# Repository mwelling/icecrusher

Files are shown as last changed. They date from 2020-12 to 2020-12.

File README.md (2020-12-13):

# icebreaker++ RAM

The icebreaker is a friendly development board for the iCE40: [https://github.com/icebreaker-fpga/icebreaker](https://github.com/icebreaker-fpga/icebreaker)

---

## What is it

The icebreaker is a really nice and handy little board. But it has a small flaw, the ice40 FPGA it uses is quite smol, while it's often fun to see the exciting projects people pull off with 5k LUTs. Sometimes it's handy to have a bit of extra space available whe experimenting.

 - The board design takes the original designs and simply replaces the fpga with an ECP5.
 - The FTDI's second port is connected directly to extra I/O pins.
 - Each PMOD is connected to support 4x differential-pairs each.
 - Features footprints for both PSRAM and HyperRAM.

## Folder structure

```
kicad-src: KiCad v6 source files
production:
 - Gerbers:      [project]_gerbers.zip
 - Schematic:    [project].pdf
 - Board render: [project].png
```

## Render

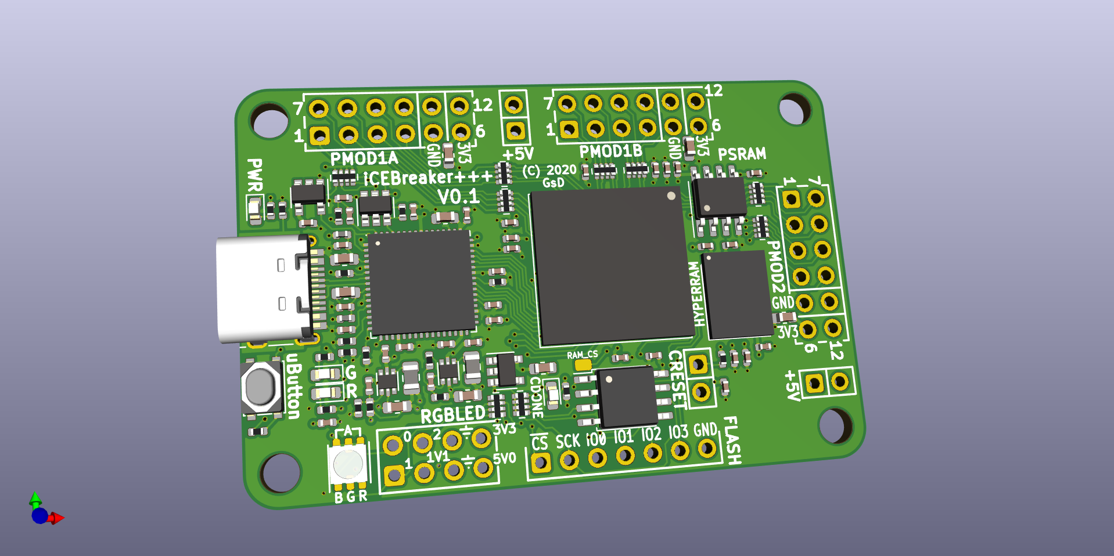
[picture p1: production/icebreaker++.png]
Render


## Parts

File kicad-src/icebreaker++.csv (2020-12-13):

C1 C4 C10 C12 C13 C14 C16 C17 C18 C19 C20 C21 C22 | 13 | 100n | Capacitor_SMD:C_0402_1005Metric |  | cap-cer-0402-100n | ANY
C15 C23 | 2 | 4.7uF | Capacitor_SMD:C_0402_1005Metric | ~ |  |  |  |  |  |  |  | Yageo | CC0402KRX5R6BB475
C2 C3 C5 C8 C11 C35 C36 C37 C38 C39 C40 C41 C42 C43 | 14 | 0.1uF | Capacitor_SMD:C_0402_1005Metric | ~
C24 C28 C29 | 3 | 10uF | Capacitor_SMD:C_0603_1608Metric | ~ |  |  |  |  |  |  |  | Yageo | CC0603KRX5R5BB106
C25 C30 C31 | 3 | 1uF | Capacitor_SMD:C_0402_1005Metric | ~ |  |  |  |  |  |  |  | Yageo | CC0402KRX5R6BB105
C26 C27 | 2 | 6.8pF | Capacitor_SMD:C_0402_1005Metric | ~ |  |  |  |  |  |  |  | Yageo | CC0402CRNPO9BN6R8
C32 C33 C34 | 3 | DNP | Capacitor_SMD:C_0603_1608Metric |  | cap-cer-0603-10u | ANY | YES
C6 C7 C9 | 3 | 4u7 | Capacitor_SMD:C_0603_1608Metric |  | cap-cer-0402-4u7 | ANY
D1 D4 | 2 | GRN | LED_SMD:LED_0603_1608Metric |  | led-0603-grn | ANY
D11 | 1 | LED_RGB | pkl_led:LED_Cree_PLCC6_3.4x3.4mm | ~ |  |  | YES | CLX6F-FKC | Cree
D3 | 1 | BLU | LED_SMD:LED_0603_1608Metric |  | led-0603-blu | ANY
D5 | 1 | RED | LED_SMD:LED_0603_1608Metric |  | led-0603-red | ANY
J20 | 1 | Flash | Connector_PinHeader_2.54mm:PinHeader_1x07_P2.54mm_Vertical | ~ | conn-th-01in-7-1-hdr | ANY
J21 J23 J27 | 3 | PMOD | gsd-footprints:PMOD_Angled_2x06 | ~ | conn-th-01in-6-2-rec-ra | ANY
J22 J26 | 2 | 5V AUX | Connector_PinHeader_2.54mm:PinHeader_2x01_P2.54mm_Vertical | ~ | conn-th-01in-2-1-hdr | ANY
J24 | 1 | USB_C_Receptacle_USB2.0 | Connector_USB:USB_C_Receptacle_HRO_TYPE-C-31-M-12 | https://www.usb.org/sites/default/files/documents/usb_type-c.zip
J25 | 1 | RGB Led | Connector_PinHeader_2.54mm:PinHeader_2x04_P2.54mm_Vertical | ~ | conn-th-01in-4-2-hdr | ANY
J28 | 1 | CRESET | Connector_PinHeader_2.54mm:PinHeader_2x01_P2.54mm_Vertical | ~ | conn-th-01in-2-1-hdr | ANY | YES
L1 L2 | 2 | 600 | Inductor_SMD:L_0402_1005Metric |  | ferrite-0402-600 | ANY
L3 L4 | 2 | 2.2uH | Inductor_SMD:L_0805_2012Metric | ~ |  |  |  |  |  |  |  | Sunltech Tech | SLM20122R2MIT
P2 P3 P4 P5 | 4 | UP | pkl_pads:PAD_SMD_1x2.65 |  |  | ANY
P6 | 1 | RAM_CS | pkl_pads:PAD_SMD_1x1.5 |  |  | ANY
R1 | 1 | 1M | Resistor_SMD:R_0402_1005Metric |  | res-0402-1m | ANY
R10 | 1 | 210k | Resistor_SMD:R_0402_1005Metric | ~ |  |  |  |  |  |  |  | Yageo | RC0402FR-07210KL | 1%
R2 R11 | 2 | 10k | Resistor_SMD:R_Array_Convex_4x0402 | ~
R20 | 1 | 1k | Resistor_SMD:R_0402_1005Metric |  | res-0402-10k | ANY
R21 R22 | 2 | 5.1k | Resistor_SMD:R_0402_1005Metric | ~
R23 | 1 | 47k | Resistor_SMD:R_0402_1005Metric | ~ |  |  |  |  |  |  |  | Yageo | RC0402FR-0747KL
R24 | 1 | 84k5 | Resistor_SMD:R_0402_1005Metric | ~ |  |  |  |  |  |  |  | Yageo | RC0402FR-0784K5L | 1%
R26 | 1 | 100k | Resistor_SMD:R_0402_1005Metric | ~ |  |  |  |  |  |  |  | Yageo | RC0402FR-07100KL | 1%
R3 R4 R7 R16 R17 R18 R27 | 7 | 33R | Resistor_SMD:R_Array_Convex_4x0402 | ~
R5 R14 R15 | 3 | 330E | Resistor_SMD:R_0402_1005Metric |  | res-0402-330 | ANY
R6 R12 | 2 | 2k2 | Resistor_SMD:R_0402_1005Metric |  | res-0402-2k2 | ANY
R8 | 1 | 12k | Resistor_SMD:R_0402_1005Metric |  | res-0402-12k | ANY |  |  |  | 1% current reference
R9 R13 R19 R25 | 4 | 10k | Resistor_SMD:R_0402_1005Metric |  | res-0402-10k | ANY
SW1 | 1 | TACT | Button_Switch_SMD:SW_SPST_PTS810 |  | sw-tact-top-3x4x25
U1 | 1 | 93C46B-SOT-23-6 | Package_TO_SOT_SMD:SOT-23-6 | http://ww1.microchip.com/downloads/en/DeviceDoc/20001749K.pdf | eeprom-sot23-6-93c46b | ANY |  | 93C46B |  | EEPROM 1KBit 2MHz SOT-23-6
U10 | 1 | IS66WVH16M8ALL | gsd-footprints:BGA-24_8.0x6.0mm_Layout5x5_P0.8mm_Pad0.35mm_NSMD |  |  |  |  |  |  |  |  | ISSI, Integrated Silicon Solution Inc | IS66WVH16M8ALL-166B1LI |  | 706-1548-ND
U2 | 1 | FT2232H | Package_DFN_QFN:QFN-64-1EP_9x9mm_P0.5mm_EP4.35x4.35mm | https://www.ftdichip.com/Support/Documents/DataSheets/ICs/DS_FT2232H.pdf
U3 | 1 | W25Q32JVSS | Package_SO:SOIC-8_5.23x5.23mm_P1.27mm | http://www.winbond.com/resource-files/w25q32jv%20revg%2003272018%20plus.pdf
U4 U5 | 2 | TLV62569DRL | Package_TO_SOT_SMD:SOT-666 | http://www.ti.com/lit/ds/symlink/tlv62569.pdf |  |  |  |  |  |  |  | Texas Instruments | TLV62569DRLR
U6 | 1 | TLV713285PDBV | Package_TO_SOT_SMD:SOT-23-5 | http://www.ti.com/lit/ds/symlink/tlv713p.pdf
U7 | 1 | 12MHz | Package_TO_SOT_SMD:SOT-23-5 |  | xtal-sot23-5-12mhz-osc | ANY
U8 | 1 | ECP5U-12-CABGA256 | Package_BGA:BGA-256_14.0x14.0mm_Layout16x16_P0.8mm_Ball0.45mm_Pad0.32mm_NSMD |  |  |  |  |  |  |  | ECP5U_12
U9 | 1 | LY68L6400SLIT | Package_SO:SOIC-8_3.9x4.9mm_P1.27mm | http://www.winbond.com/resource-files/w25q32jv%20revg%2003272018%20plus.pdf

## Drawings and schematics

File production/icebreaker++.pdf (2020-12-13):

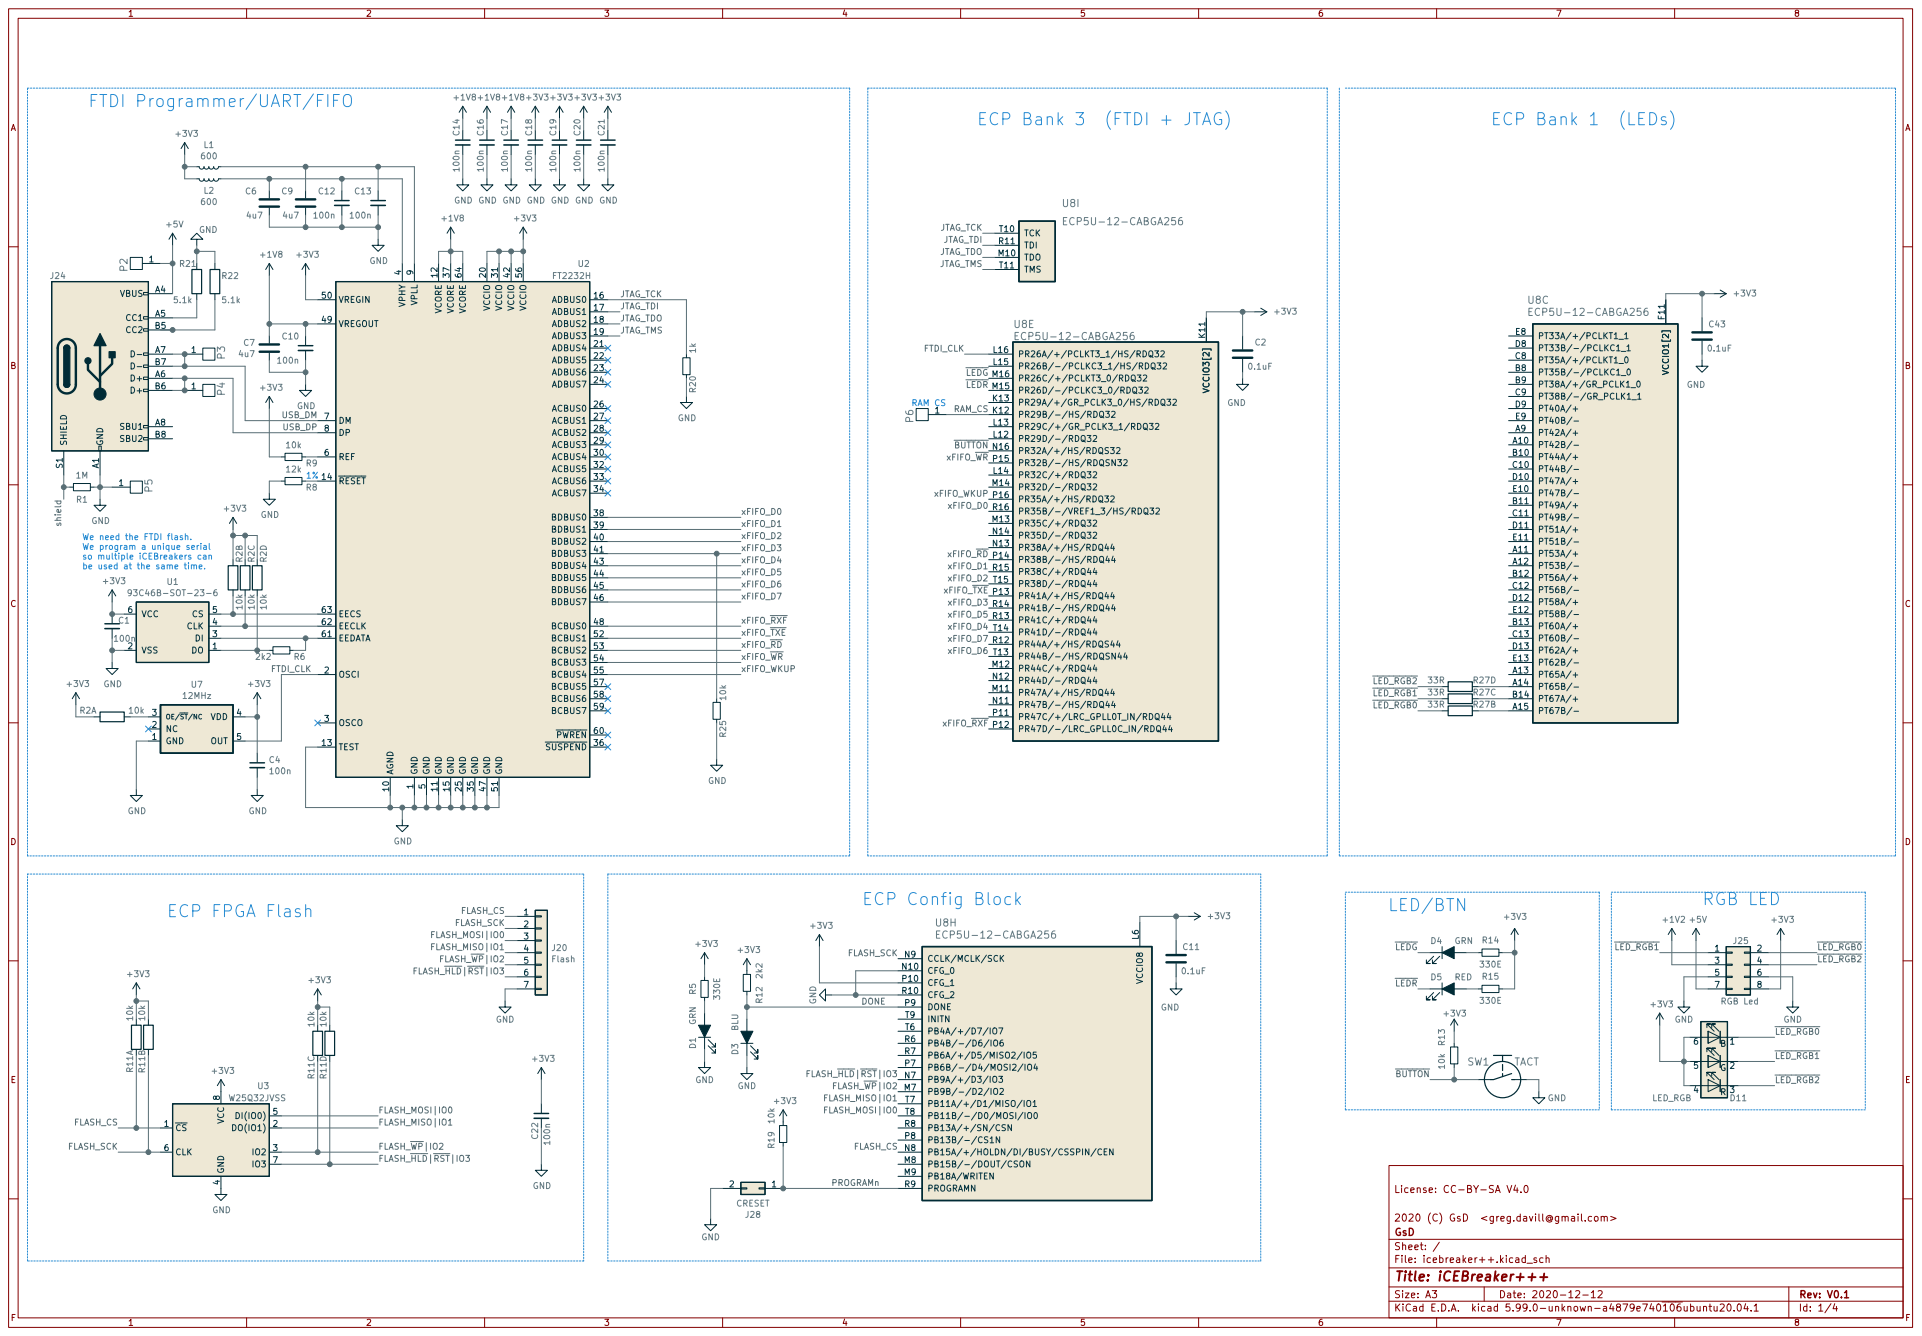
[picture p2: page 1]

ECP Bank 3 (FTDI + JTAG)

1 AGND 10 GND 11 VCORE 12 TEST 13 ~RESET 14 GND 15 ADBUS0 16 ADBUS1 17 ADBUS2 18 ADBUS3 19 OSCI 2 VCCIO 20 ADBUS4 21 ADBUS5 22 ADBUS6 23 ADBUS7 24 GND 25 ACBUS0 26 ACBUS1 27 ACBUS2 28 ACBUS3 29 OSCO 3 ACBUS4 30 VCCIO 31 ACBUS5 32 ACBUS6 33 ACBUS7 34 GND 35 ~SUSPEND 36 VCORE 37 BDBUS0 38 BDBUS1 39 VPHY

4 BDBUS2 40 BDBUS3 41 VCCIO 42 BDBUS4 43 BDBUS5 44 BDBUS6 45 BDBUS7 46 GND 47 BCBUS0 48 VREGOUT 49 GND

5 VREGIN 50 GND 51 BCBUS1 52 BCBUS2 53 BCBUS3 54 BCBUS4 55 VCCIO 56 BCBUS5 57 BCBUS6 58 BCBUS7 59 REF 6 ~PWREN 60 EEDATA 61 EECLK 62 EECS 63 VCORE 64 DM 7 DP 8 VPLL

We need the FTDI flash. We program a unique serial

so multiple iCEBreakers can
be used at the same time. ECP FPGA Flash

2020 (C) GsD <greg.davill@gmail.com>
File: icebreaker++.kicad_sch Sheet: / GsD

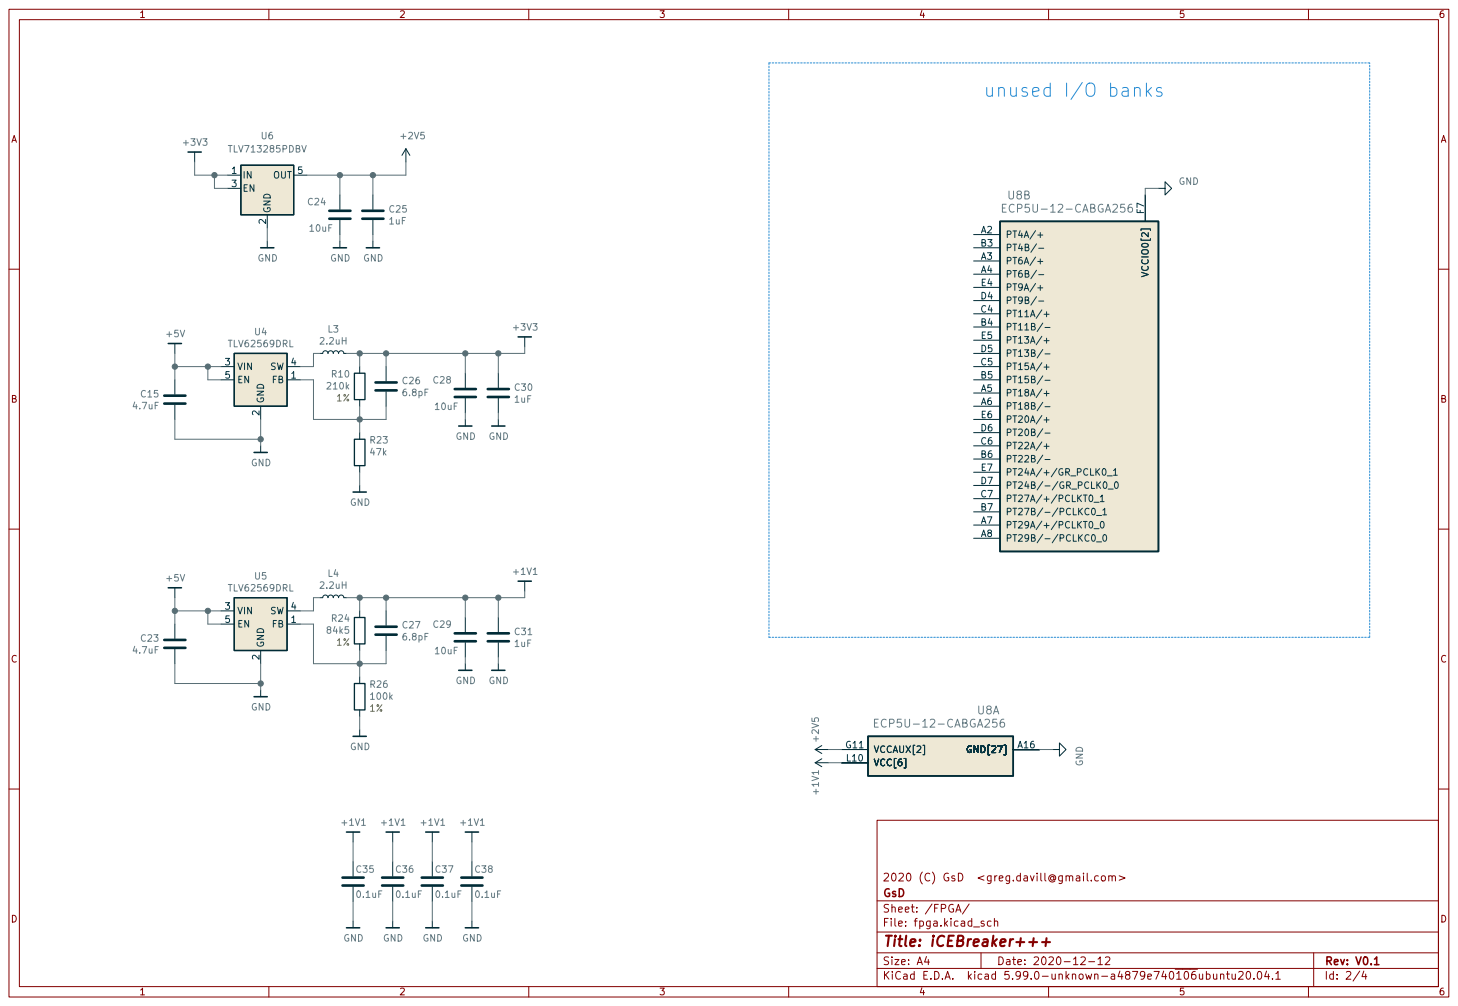
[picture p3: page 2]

2020 (C) GsD <greg.davill@gmail.com> GND

File: fpga.kicad_sch Sheet: /FPGA/ GsD

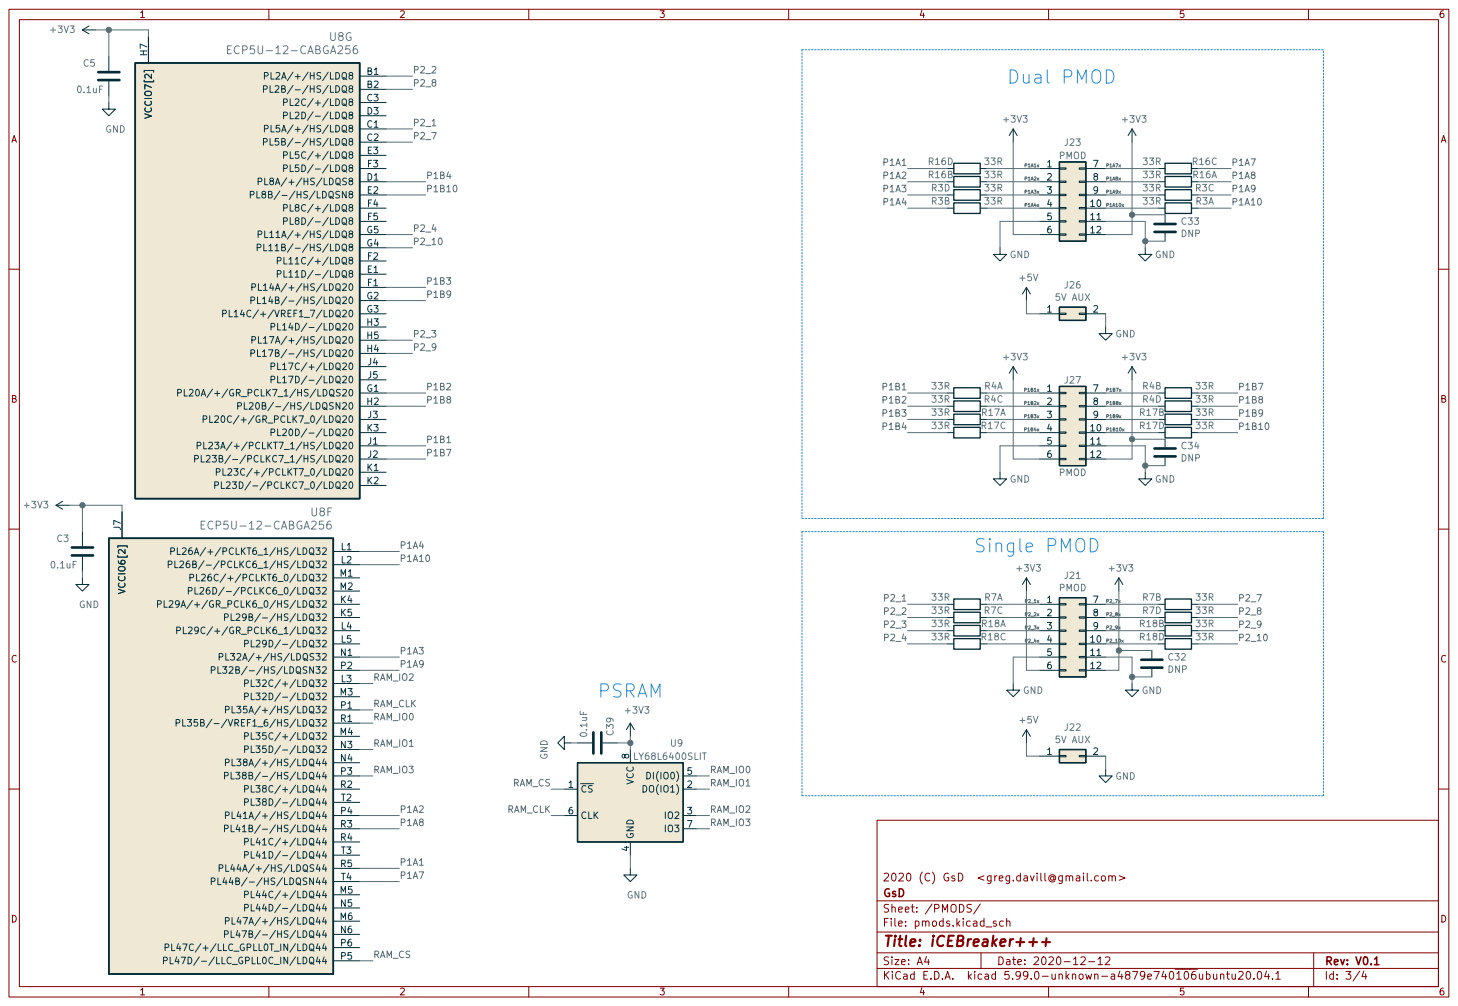
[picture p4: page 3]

2020 (C) GsD <greg.davill@gmail.com> GND

File: pmods.kicad_sch Sheet: /PMODS/ GsD

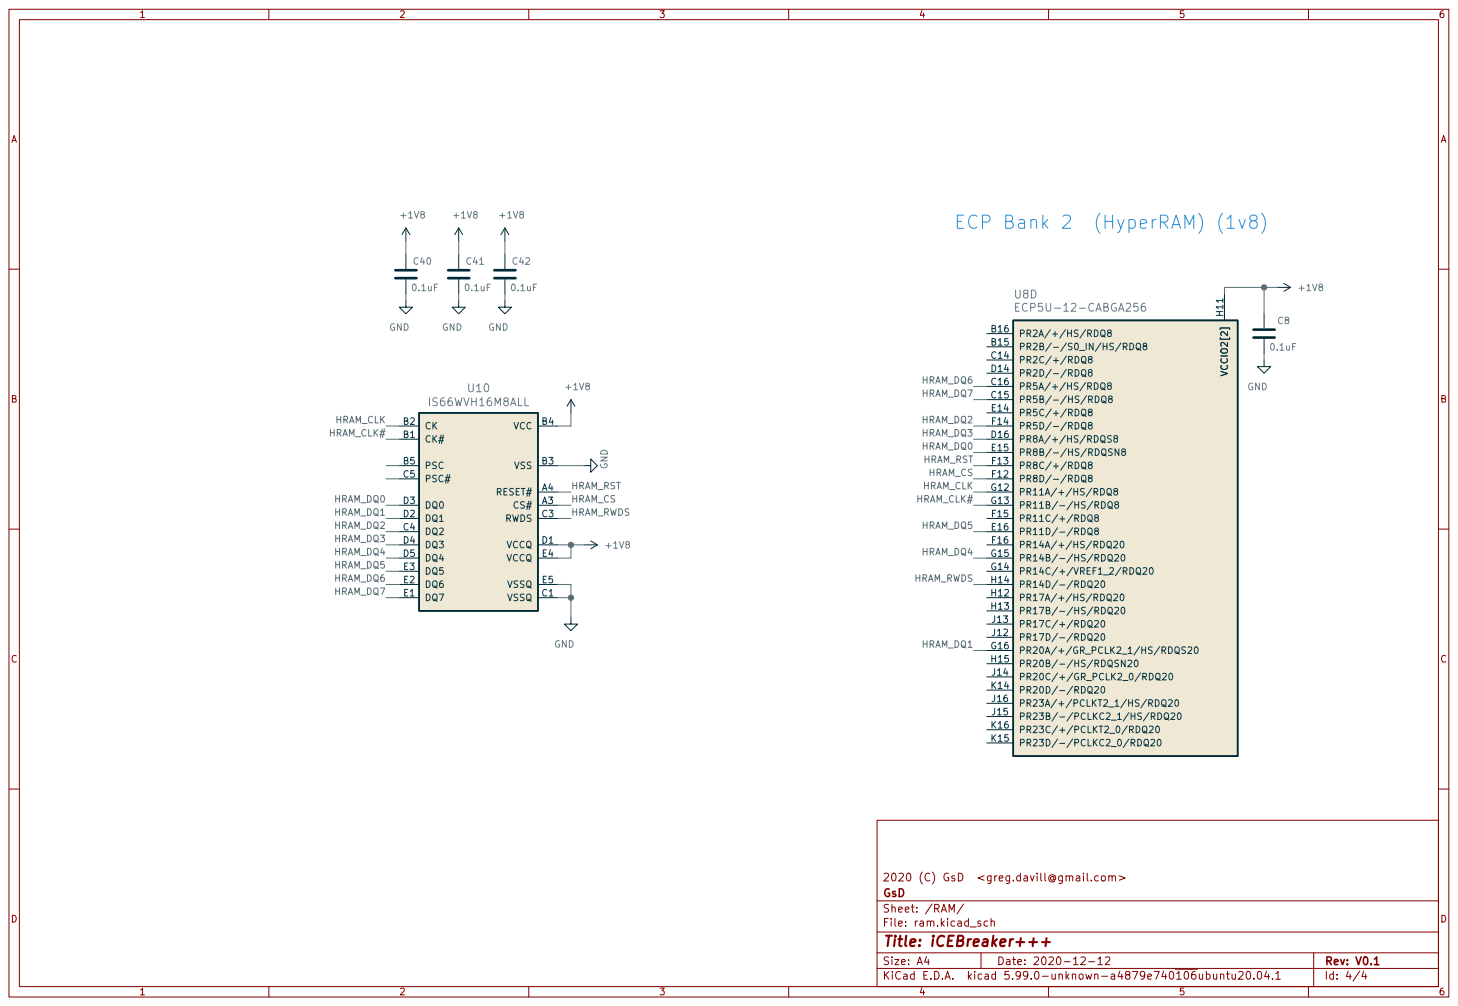
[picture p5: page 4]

2020 (C) GsD <greg.davill@gmail.com>
File: ram.kicad_sch Sheet: /RAM/ GsD

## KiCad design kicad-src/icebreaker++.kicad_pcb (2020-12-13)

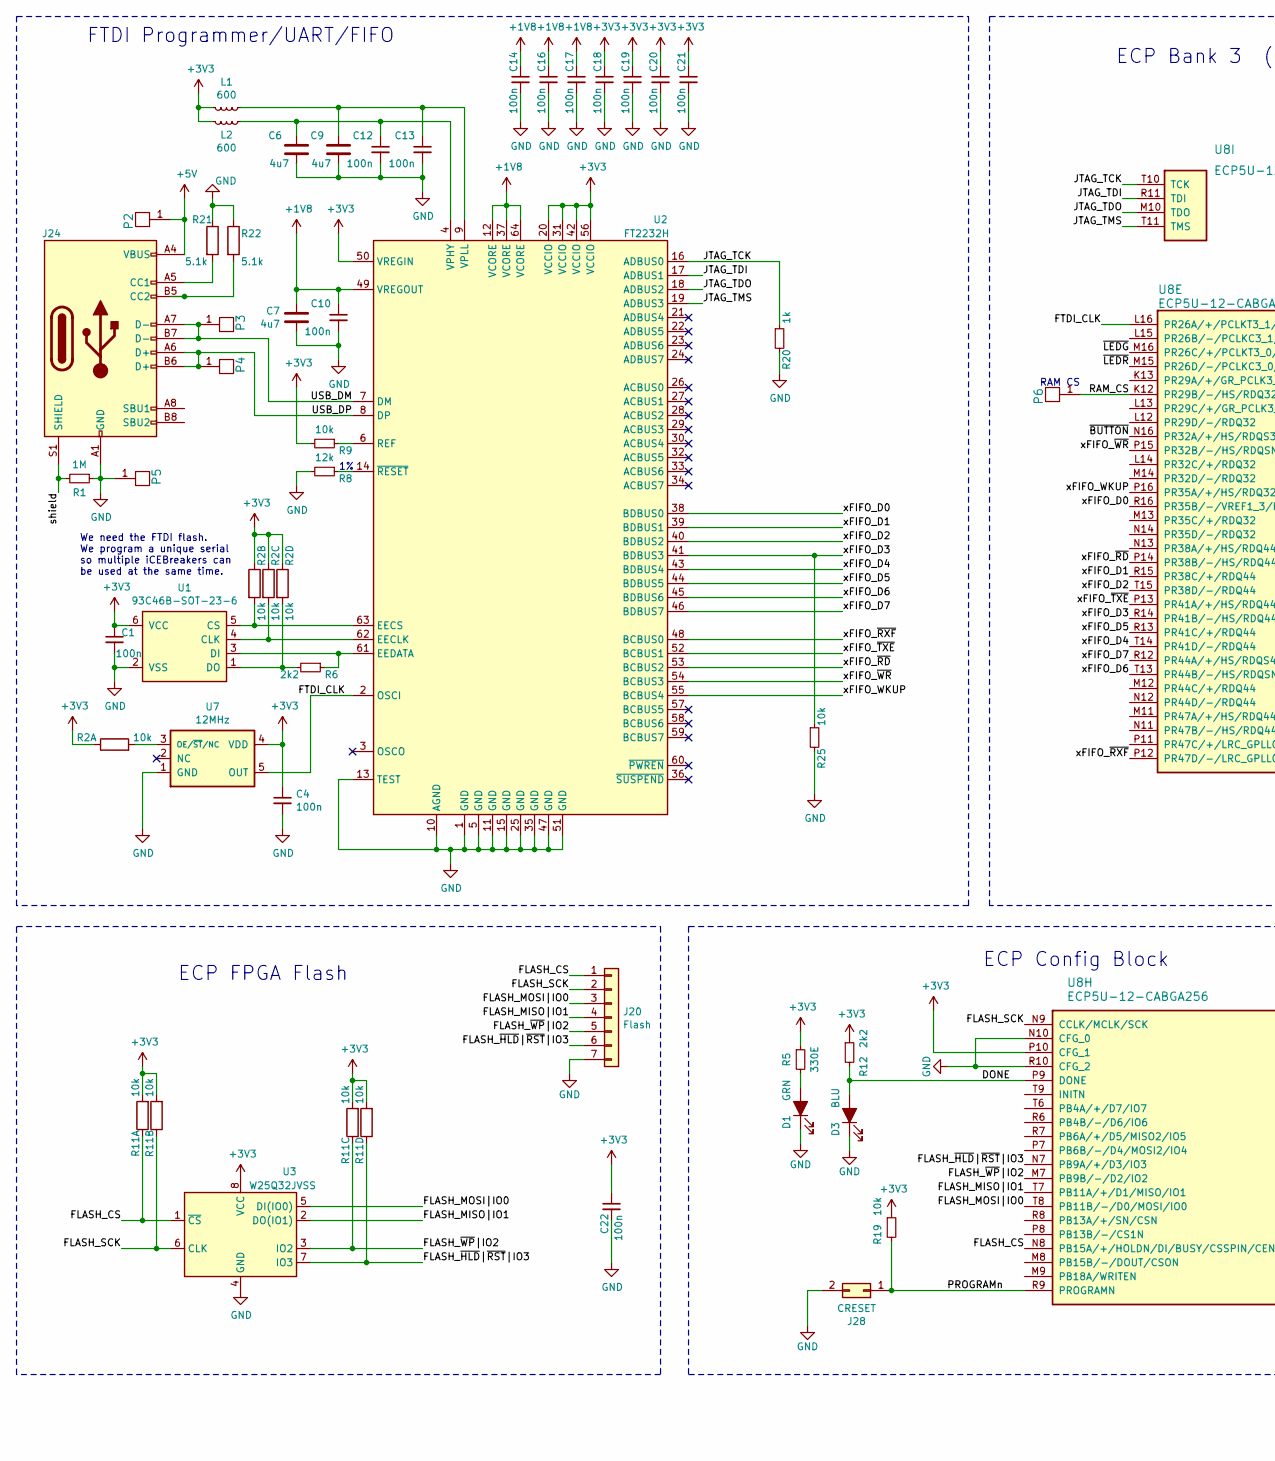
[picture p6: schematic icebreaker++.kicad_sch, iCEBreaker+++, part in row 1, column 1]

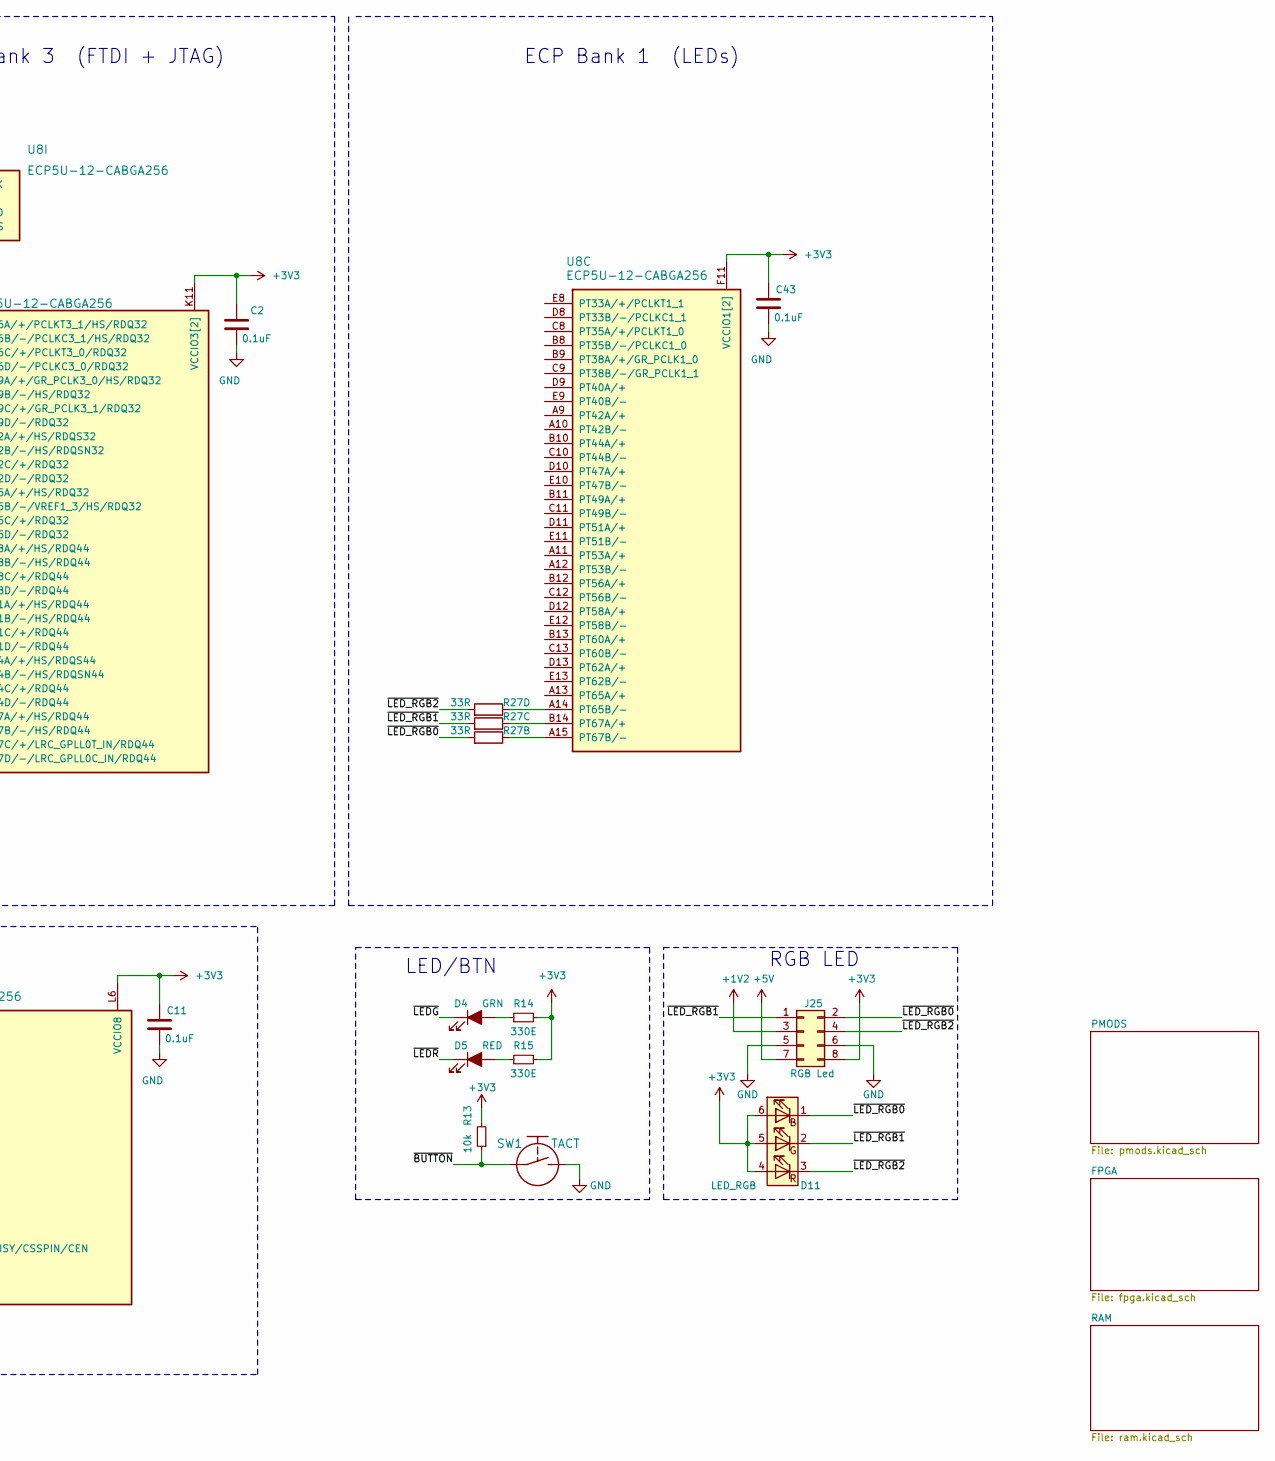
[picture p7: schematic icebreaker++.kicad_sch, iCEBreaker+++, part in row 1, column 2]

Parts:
C1, C4, C10, C12, C13, C14, C16, C17, C18, C19, C20, C21, C22: 100n; C_0402_1005Metric
C2, C11, C43: 0.1uF; C_0402_1005Metric
C6, C7, C9: 4u7; C_0603_1608Metric
D1, D4: GRN; LED_0603_1608Metric
D3: BLU; LED_0603_1608Metric
D5: RED; LED_0603_1608Metric
D11: LED_RGB; LED_Cree_PLCC6_3.4x3.4mm
J20: Flash; PinHeader_1x07_P2.54mm_Vertical
J24: USB_C_Receptacle_USB2.0; USB_C_Receptacle_HRO_TYPE-C-31-M-12
J25: RGB Led; PinHeader_2x04_P2.54mm_Vertical
J28: CRESET; PinHeader_2x01_P2.54mm_Vertical
L1, L2: 600; L_0402_1005Metric
P2, P3, P4, P5: UP; PAD_SMD_1x2.65
P6: RAM_CS; PAD_SMD_1x1.5
R1: 1M; R_0402_1005Metric
R2, R11: 10k; R_Array_Convex_4x0402
R5, R14, R15: 330E; R_0402_1005Metric
R6, R12: 2k2; R_0402_1005Metric
R8: 12k; R_0402_1005Metric
R9, R13, R19, R25: 10k; R_0402_1005Metric
R20: 1k; R_0402_1005Metric
R21, R22: 5.1k; R_0402_1005Metric
R27: 33R; R_Array_Convex_4x0402
SW1: TACT; SW_SPST_PTS810
U1: 93C46B-SOT-23-6; SOT-23-6
U2: FT2232H; QFN-64-1EP_9x9mm_P0.5mm_EP4.35x4.35mm
U3: W25Q32JVSS; SOIC-8_5.23x5.23mm_P1.27mm
U7: 12MHz; SOT-23-5
U8: ECP5U-12-CABGA256; BGA-256_14.0x14.0mm_Layout16x16_P0.8mm_Ball0.45mm_Pad0.32mm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

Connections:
+1V2: J25.3
+1V8: C7.1, C10.1, C14.1, C16.1, C17.1, U2.12 (VCORE), U2.37 (VCORE), U2.49 (VREGOUT), U2.64 (VCORE); also elsewhere on the board
+3V3: C1.1, C2.1, C4.1, C11.1, C18.1, C19.1, C20.1, C21.1, C22.1, C43.1, D11.4 (BA), D11.5 (GA), D11.6 (RA), J25.8, L1.1, L2.1, R2.5, R2.6, R2.7, R2.8, R5.1, R9.2, R11.1, R11.2, R11.3, R11.4, R12.1, R13.2, R14.2, R15.2, R19.1, U1.6 (VCC), U2.20 (VCCIO), U2.31 (VCCIO), U2.42 (VCCIO), U2.50 (VREGIN), U2.56 (VCCIO), U3.8 (VCC), U7.4 (VDD), U8.F10 (VCCIO1[2]), U8.F11 (VCCIO1[2]), U8.K11 (VCCIO3[2]), U8.L6 (VCCIO8), U8.L11 (VCCIO3[2]), U8.P10 (CFG_1); also elsewhere on the board
+5V: J24.A4 (VBUS), J24.A9 (VBUS), J24.B4 (VBUS), J24.B9 (VBUS), J25.7, P2.1 (PAD); also elsewhere on the board
/DONE: D3.2 (A), R12.2, U8.P9 (DONE)
/FLASH_CS: J20.1, R11.8, U3.1 (~CS), U8.N8 (PB15A/+/HOLDN/DI/BUSY/CSSPIN/CEN)
/FLASH_MISO|IO1: J20.4, U3.2 (DO(IO1)), U8.T7 (PB11A/+/D1/MISO/IO1)
/FLASH_MOSI|IO0: J20.3, U3.5 (DI(IO0)), U8.T8 (PB11B/-/D0/MOSI/IO0)
/FLASH_SCK: J20.2, R11.7, U3.6 (CLK), U8.N9 (CCLK/MCLK/SCK)
/FLASH_~HLD~|~RST~|IO3: J20.6, R11.5, U3.7 (IO3), U8.N7 (PB9A/+/D3/IO3)
/FLASH_~WP~|IO2: J20.5, R11.6, U3.3 (IO2), U8.M7 (PB9B/-/D2/IO2)
/FTDI_CLK: U2.2 (OSCI), U7.5 (OUT), U8.L16 (PR26A/+/PCLKT3_1/HS/RDQ32)
/JTAG_TCK: R20.1, U2.16 (ADBUS0), U8.T10 (TCK)
/JTAG_TDI: U2.17 (ADBUS1), U8.R11 (TDI)
/JTAG_TDO: U2.18 (ADBUS2), U8.M10 (TDO)
/JTAG_TMS: U2.19 (ADBUS3), U8.T11 (TMS)
/PROGRAMn: J28.1, R19.2, U8.R9 (PROGRAMN)
/RAM_CS: P6.1 (PAD), U8.K12 (PR29B/-/HS/RDQ32)
/USB_DM: J24.A7 (D-), J24.B7 (D-), P3.1 (PAD), U2.7 (DM)
/USB_DP: J24.A6 (D+), J24.B6 (D+), P4.1 (PAD), U2.8 (DP)
/shield: J24.S1 (SHIELD), R1.2
/xFIFO_D0: U2.38 (BDBUS0), U8.R16 (PR35B/-/VREF1_3/HS/RDQ32)
/xFIFO_D1: U2.39 (BDBUS1), U8.R15 (PR38C/+/RDQ44)
/xFIFO_D2: U2.40 (BDBUS2), U8.T15 (PR38D/-/RDQ44)
/xFIFO_D3: R25.1, U2.41 (BDBUS3), U8.R14 (PR41B/-/HS/RDQ44)
/xFIFO_D4: U2.43 (BDBUS4), U8.T14 (PR41D/-/RDQ44)
/xFIFO_D5: U2.44 (BDBUS5), U8.R13 (PR41C/+/RDQ44)
/xFIFO_D6: U2.45 (BDBUS6), U8.T13 (PR44B/-/HS/RDQSN44)
/xFIFO_D7: U2.46 (BDBUS7), U8.R12 (PR44A/+/HS/RDQS44)
/xFIFO_WKUP: U2.55 (BCBUS4), U8.P16 (PR35A/+/HS/RDQ32)
/xFIFO_~RD: U2.53 (BCBUS2), U8.P14 (PR38B/-/HS/RDQ44)
/xFIFO_~RXF: U2.48 (BCBUS0), U8.P12 (PR47D/-/LRC_GPLL0C_IN/RDQ44)
/xFIFO_~TXE: U2.52 (BCBUS1), U8.P13 (PR41A/+/HS/RDQ44)
/xFIFO_~WR: U2.54 (BCBUS3), U8.P15 (PR32B/-/HS/RDQSN32)
/~BUTTON: R13.1, SW1.1, U8.N16 (PR32A/+/HS/RDQS32)
/~LEDG: D4.1 (K), U8.M16 (PR26C/+/PCLKT3_0/RDQ32)
/~LEDR: D5.1 (K), U8.M15 (PR26D/-/PCLKC3_0/RDQ32)
/~LED_RGB0: D11.1 (RK), J25.2, R27.2
/~LED_RGB1: D11.2 (GK), J25.1, R27.3
/~LED_RGB2: D11.3 (BK), J25.4, R27.4
GND: C1.2, C2.2, C4.2, C6.2, C7.2, C9.2, C10.2, C11.2, C12.2, C13.2, C14.2, C16.2, C17.2, C18.2, C19.2, C20.2, C21.2, C22.2, C43.2, D1.1 (K), D3.1 (K), J20.7, J24.A1 (GND), J24.A12 (GND), J24.B1 (GND), J24.B12 (GND), J25.5, J25.6, J28.2, P5.1 (PAD), R1.1, R8.2, R20.2, R21.1, R22.1, R25.2, SW1.2, U1.2 (VSS), U2.1 (GND), U2.5 (GND), U2.10 (AGND), U2.11 (GND), U2.13 (TEST), U2.15 (GND), U2.25 (GND), U2.35 (GND), U2.47 (GND), U2.51 (GND), U2.65, U3.4 (GND), U7.1 (GND), U8.N10 (CFG_0), U8.R10 (CFG_2); also elsewhere on the board
unnamed: C6.1, C12.1, L2.2, U2.4 (VPHY)
unnamed: C9.1, C13.1, L1.2, U2.9 (VPLL)
unnamed: D1.2 (A), R5.2
unnamed: D4.2 (A), R14.1
unnamed: D5.2 (A), R15.1
unnamed: J24.A5 (CC1), R21.2
unnamed: J24.B5 (CC2), R22.2
unnamed: R2.1, U7.3 (OE/~ST~/NC)
unnamed: R2.2, U1.5 (CS), U2.63 (EECS)
unnamed: R2.3, U1.4 (CLK), U2.62 (EECLK)
unnamed: R2.4, R6.2, U1.1 (DO)
unnamed: R6.1, U1.3 (DI), U2.61 (EEDATA)
unnamed: R8.1, U2.14 (~RESET)
unnamed: R9.1, U2.6 (REF)
unnamed: R27.5, U8.A14 (PT65B/-)
unnamed: R27.7, U8.A15 (PT67B/-)
unnamed: R27.6, U8.B14 (PT67A/+)
no_connect_265: U2.21 (ADBUS4)
no_connect_266: U2.22 (ADBUS5)
no_connect_267: U2.23 (ADBUS6)
no_connect_268: U2.24 (ADBUS7)
no_connect_269: U2.26 (ACBUS0)
no_connect_270: U2.27 (ACBUS1)
no_connect_271: U2.28 (ACBUS2)
no_connect_272: U2.29 (ACBUS3)
no_connect_273: U2.3 (OSCO)
no_connect_274: U2.30 (ACBUS4)
no_connect_275: U2.32 (ACBUS5)
no_connect_276: U2.33 (ACBUS6)
no_connect_277: U2.34 (ACBUS7)
no_connect_278: U2.36 (~SUSPEND)
no_connect_279: U2.57 (BCBUS5)
no_connect_280: U2.58 (BCBUS6)
no_connect_281: U2.59 (BCBUS7)
no_connect_282: U2.60 (~PWREN)
no_connect_286: U7.2 (NC)

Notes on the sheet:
We need the FTDI flash. We program a unique serial so multiple iCEBreakers can be used at the same time.
FTDI Programmer/UART/FIFO
ECP FPGA Flash
ECP Config Block
RAM CS
ECP Bank 3 (FTDI + JTAG)
LED/BTN
ECP Bank 1 (LEDs)
RGB LED

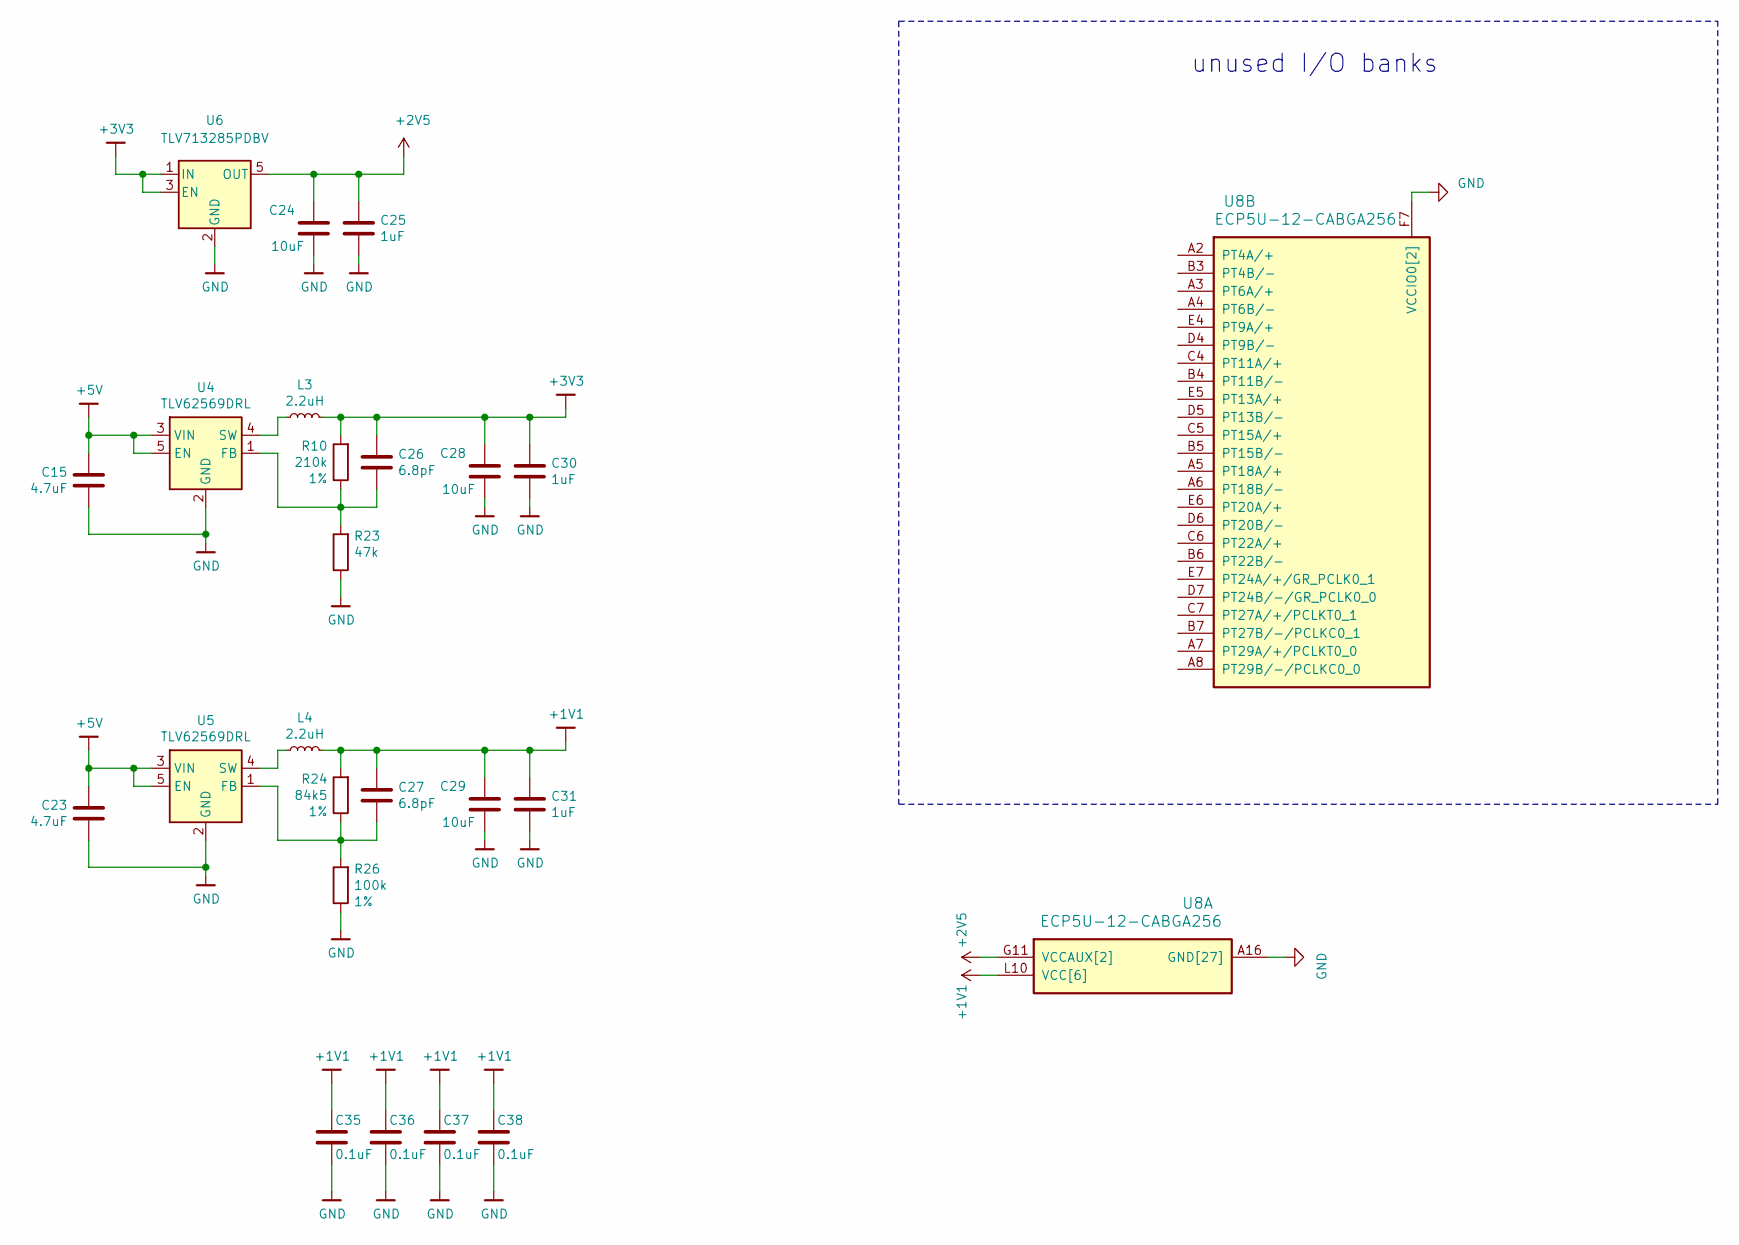
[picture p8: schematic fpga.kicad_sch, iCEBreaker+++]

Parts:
C15, C23: 4.7uF; C_0402_1005Metric
C24, C28, C29: 10uF; C_0603_1608Metric
C25, C30, C31: 1uF; C_0402_1005Metric
C26, C27: 6.8pF; C_0402_1005Metric
C35, C36, C37, C38: 0.1uF; C_0402_1005Metric
L3, L4: 2.2uH; L_0805_2012Metric
R10: 210k; R_0402_1005Metric
R23: 47k; R_0402_1005Metric
R24: 84k5; R_0402_1005Metric
R26: 100k; R_0402_1005Metric
U4, U5: TLV62569DRL; SOT-666
U6: TLV713285PDBV; SOT-23-5
U8: ECP5U-12-CABGA256; BGA-256_14.0x14.0mm_Layout16x16_P0.8mm_Ball0.45mm_Pad0.32mm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

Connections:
+1V1: C27.1, C29.1, C31.1, C35.1, C36.1, C37.1, C38.1, L4.2, R24.2, U8.G6 (VCC[6]), U8.G7 (VCC[6]), U8.G9 (VCC[6]), U8.L8 (VCC[6]), U8.L9 (VCC[6]), U8.L10 (VCC[6])
+2V5: C24.1, C25.1, U6.5 (OUT), U8.G11 (VCCAUX[2]), U8.L7 (VCCAUX[2])
+3V3: C26.1, C28.1, C30.1, L3.2, R10.2, U6.1 (IN), U6.3 (EN); also elsewhere on the board
+5V: C15.1, C23.1, U4.3 (VIN), U4.5 (EN), U5.3 (VIN), U5.5 (EN); also elsewhere on the board
GND: C15.2, C23.2, C24.2, C25.2, C28.2, C29.2, C30.2, C31.2, C35.2, C36.2, C37.2, C38.2, R23.1, R26.1, U4.2 (GND), U5.2 (GND), U6.2 (GND), U8.A1 (GND[27]), U8.A16 (GND[27]), U8.D2 (GND[27]), U8.D15 (GND[27]), U8.F6 (VCCIO0[2]), U8.F7 (VCCIO0[2]), U8.F8 (GND[27]), U8.F9 (GND[27]), U8.G8 (GND[27]), U8.G10 (GND[27]), U8.H1 (GND[27]), U8.H8 (GND[27]), U8.H9 (GND[27]), U8.H10 (GND[27]), U8.H16 (GND[27]), U8.J8 (GND[27]), U8.J9 (GND[27]), U8.J10 (GND[27]), U8.K6 (GND[27]), U8.K7 (GND[27]), U8.K8 (GND[27]), U8.K9 (GND[27]), U8.K10 (GND[27]), U8.N2 (GND[27]), U8.N15 (GND[27]), U8.T1 (GND[27]), U8.T5 (GND[27]), U8.T12 (GND[27]), U8.T16 (GND[27]); also elsewhere on the board
unnamed: C26.2, R10.1, R23.2, U4.1 (FB)
unnamed: C27.2, R24.1, R26.2, U5.1 (FB)
unnamed: L3.1, U4.4 (SW)
unnamed: L4.1, U5.4 (SW)
no_connect_283: U4.6 (NC)
no_connect_284: U5.6 (NC)
no_connect_285: U6.4 (NC)

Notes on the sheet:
unused I/O banks

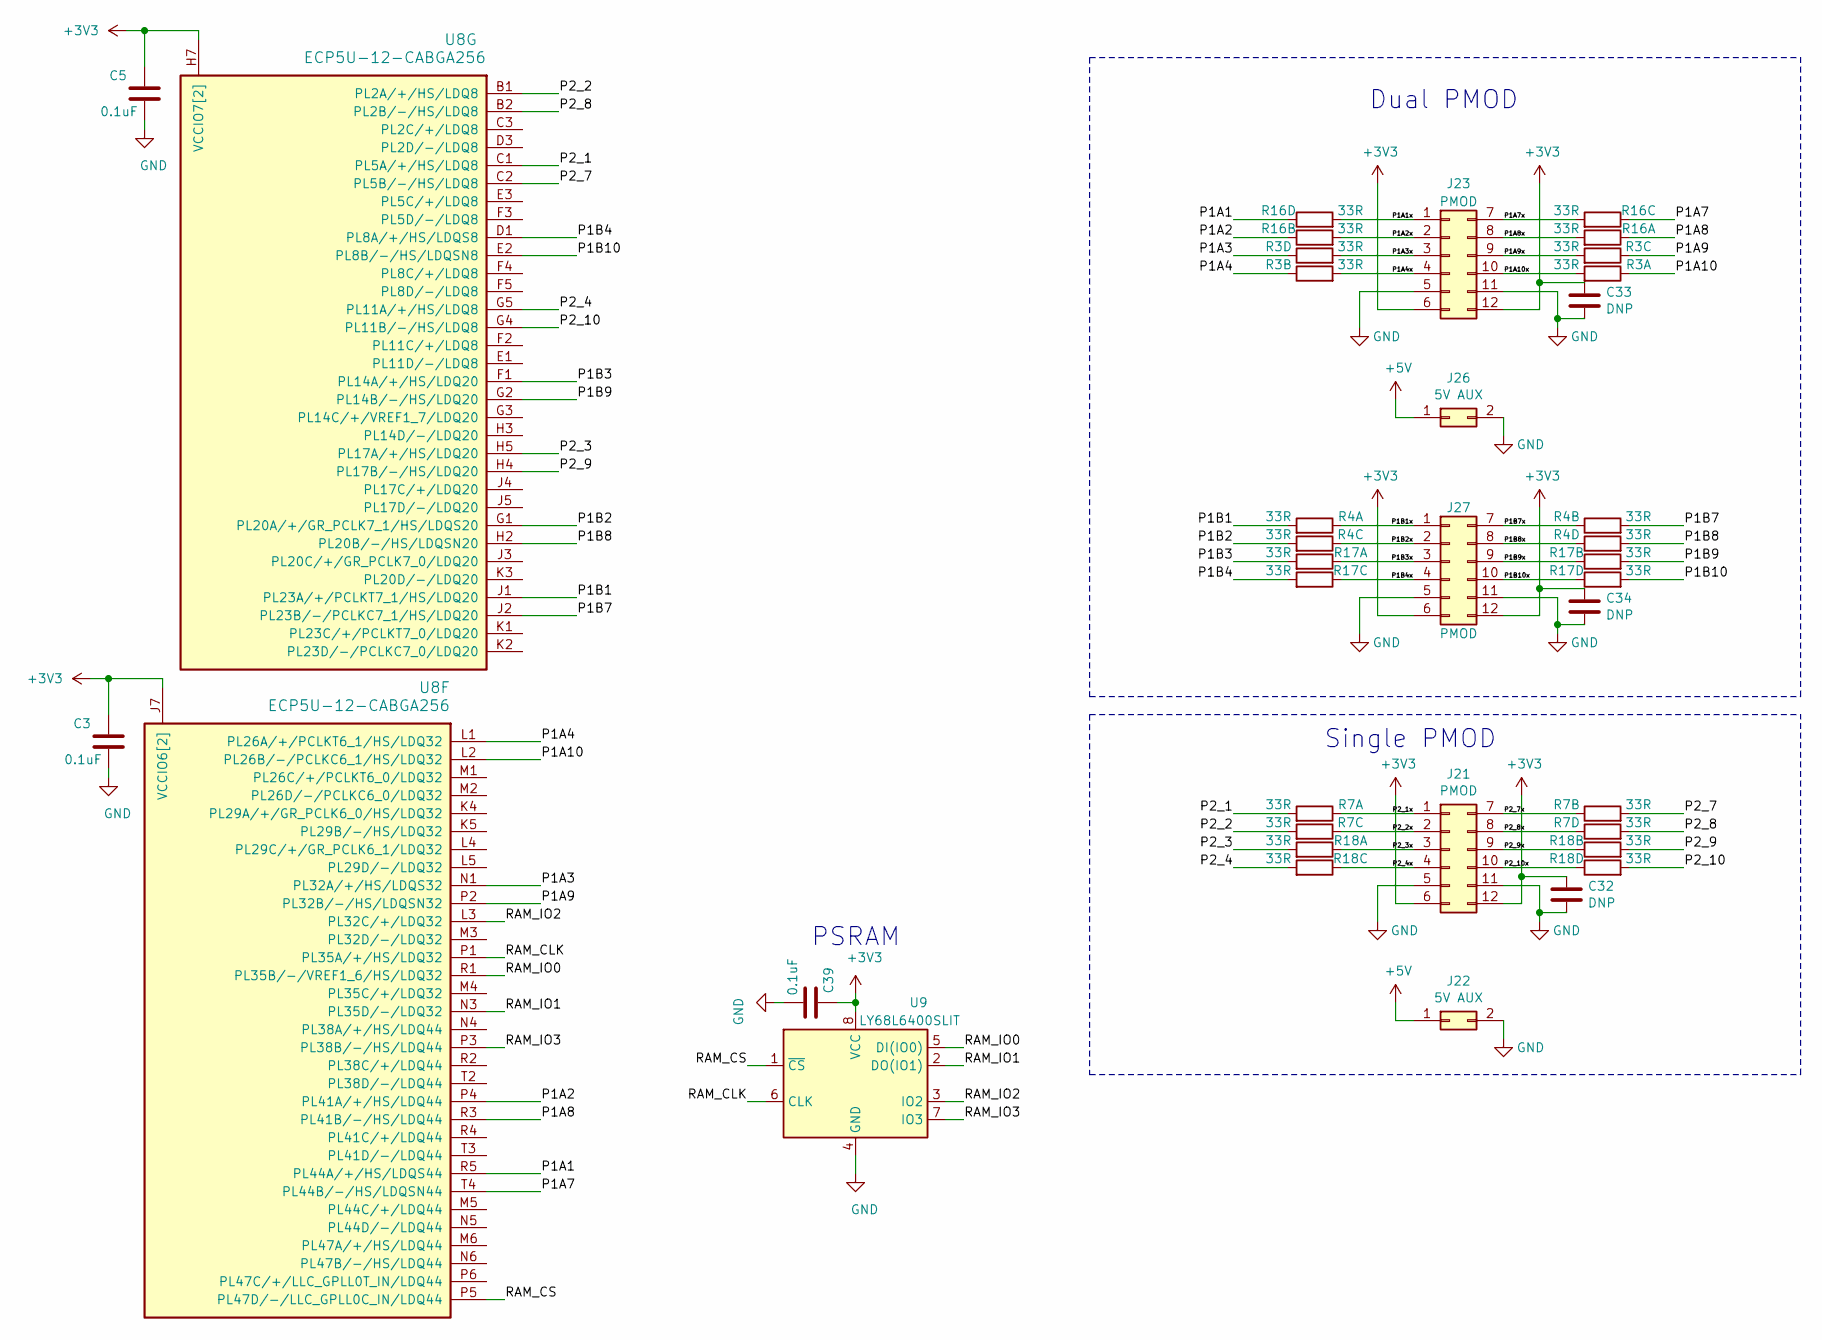
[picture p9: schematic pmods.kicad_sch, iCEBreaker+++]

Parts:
C3, C5, C39: 0.1uF; C_0402_1005Metric
C32, C33, C34: DNP; C_0603_1608Metric
J21, J23, J27: PMOD; PMOD_Angled_2x06
J22, J26: 5V AUX; PinHeader_2x01_P2.54mm_Vertical
R3, R4, R7, R16, R17, R18: 33R; R_Array_Convex_4x0402
U8: ECP5U-12-CABGA256; BGA-256_14.0x14.0mm_Layout16x16_P0.8mm_Ball0.45mm_Pad0.32mm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
U9: LY68L6400SLIT; SOIC-8_3.9x4.9mm_P1.27mm

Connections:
+3V3: C3.1, C5.1, C32.2, C33.2, C34.2, C39.1, J21.6, J21.12, J23.6, J23.12, J27.6, J27.12, U8.H6 (VCCIO7[2]), U8.H7 (VCCIO7[2]), U8.J6 (VCCIO6[2]), U8.J7 (VCCIO6[2]), U9.8 (VCC); also elsewhere on the board
+5V: J22.1, J26.1; also elsewhere on the board
/PMODS/P1A1: R16.5, U8.R5 (PL44A/+/HS/LDQS44)
/PMODS/P1A1x: J23.1, R16.4
/PMODS/P1A2: R16.7, U8.P4 (PL41A/+/HS/LDQ44)
/PMODS/P1A2x: J23.2, R16.2
/PMODS/P1A3: R3.5, U8.N1 (PL32A/+/HS/LDQS32)
/PMODS/P1A3x: J23.3, R3.4
/PMODS/P1A4: R3.7, U8.L1 (PL26A/+/PCLKT6_1/HS/LDQ32)
/PMODS/P1A4x: J23.4, R3.2
/PMODS/P1A7: R16.6, U8.T4 (PL44B/-/HS/LDQSN44)
/PMODS/P1A7x: J23.7, R16.3
/PMODS/P1A8: R16.8, U8.R3 (PL41B/-/HS/LDQ44)
/PMODS/P1A8x: J23.8, R16.1
/PMODS/P1A9: R3.6, U8.P2 (PL32B/-/HS/LDQSN32)
/PMODS/P1A9x: J23.9, R3.3
/PMODS/P1A10: R3.8, U8.L2 (PL26B/-/PCLKC6_1/HS/LDQ32)
/PMODS/P1A10x: J23.10, R3.1
/PMODS/P1B1: R4.1, U8.J1 (PL23A/+/PCLKT7_1/HS/LDQ20)
/PMODS/P1B1x: J27.1, R4.8
/PMODS/P1B2: R4.3, U8.G1 (PL20A/+/GR_PCLK7_1/HS/LDQS20)
/PMODS/P1B2x: J27.2, R4.6
/PMODS/P1B3: R17.1, U8.F1 (PL14A/+/HS/LDQ20)
/PMODS/P1B3x: J27.3, R17.8
/PMODS/P1B4: R17.3, U8.D1 (PL8A/+/HS/LDQS8)
/PMODS/P1B4x: J27.4, R17.6
/PMODS/P1B7: R4.2, U8.J2 (PL23B/-/PCLKC7_1/HS/LDQ20)
/PMODS/P1B7x: J27.7, R4.7
/PMODS/P1B8: R4.4, U8.H2 (PL20B/-/HS/LDQSN20)
/PMODS/P1B8x: J27.8, R4.5
/PMODS/P1B9: R17.2, U8.G2 (PL14B/-/HS/LDQ20)
/PMODS/P1B9x: J27.9, R17.7
/PMODS/P1B10: R17.4, U8.E2 (PL8B/-/HS/LDQSN8)
/PMODS/P1B10x: J27.10, R17.5
/PMODS/P2_1: R7.1, U8.C1 (PL5A/+/HS/LDQ8)
/PMODS/P2_1x: J21.1, R7.8
/PMODS/P2_2: R7.3, U8.B1 (PL2A/+/HS/LDQ8)
/PMODS/P2_2x: J21.2, R7.6
/PMODS/P2_3: R18.1, U8.H5 (PL17A/+/HS/LDQ20)
/PMODS/P2_3x: J21.3, R18.8
/PMODS/P2_4: R18.3, U8.G5 (PL11A/+/HS/LDQ8)
/PMODS/P2_4x: J21.4, R18.6
/PMODS/P2_7: R7.2, U8.C2 (PL5B/-/HS/LDQ8)
/PMODS/P2_7x: J21.7, R7.7
/PMODS/P2_8: R7.4, U8.B2 (PL2B/-/HS/LDQ8)
/PMODS/P2_8x: J21.8, R7.5
/PMODS/P2_9: R18.2, U8.H4 (PL17B/-/HS/LDQ20)
/PMODS/P2_9x: J21.9, R18.7
/PMODS/P2_10: R18.4, U8.G4 (PL11B/-/HS/LDQ8)
/PMODS/P2_10x: J21.10, R18.5
/PMODS/RAM_CLK: U8.P1 (PL35A/+/HS/LDQ32), U9.6 (CLK)
/PMODS/RAM_CS: U8.P5 (PL47D/-/LLC_GPLL0C_IN/LDQ44), U9.1 (~CS)
/PMODS/RAM_IO0: U8.R1 (PL35B/-/VREF1_6/HS/LDQ32), U9.5 (DI(IO0))
/PMODS/RAM_IO1: U8.N3 (PL35D/-/LDQ32), U9.2 (DO(IO1))
/PMODS/RAM_IO2: U8.L3 (PL32C/+/LDQ32), U9.3 (IO2)
/PMODS/RAM_IO3: U8.P3 (PL38B/-/HS/LDQ44), U9.7 (IO3)
GND: C3.2, C5.2, C32.1, C33.1, C34.1, C39.2, J21.5, J21.11, J22.2, J23.5, J23.11, J26.2, J27.5, J27.11, U9.4 (GND); also elsewhere on the board

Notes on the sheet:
PSRAM
Single PMOD
Dual PMOD

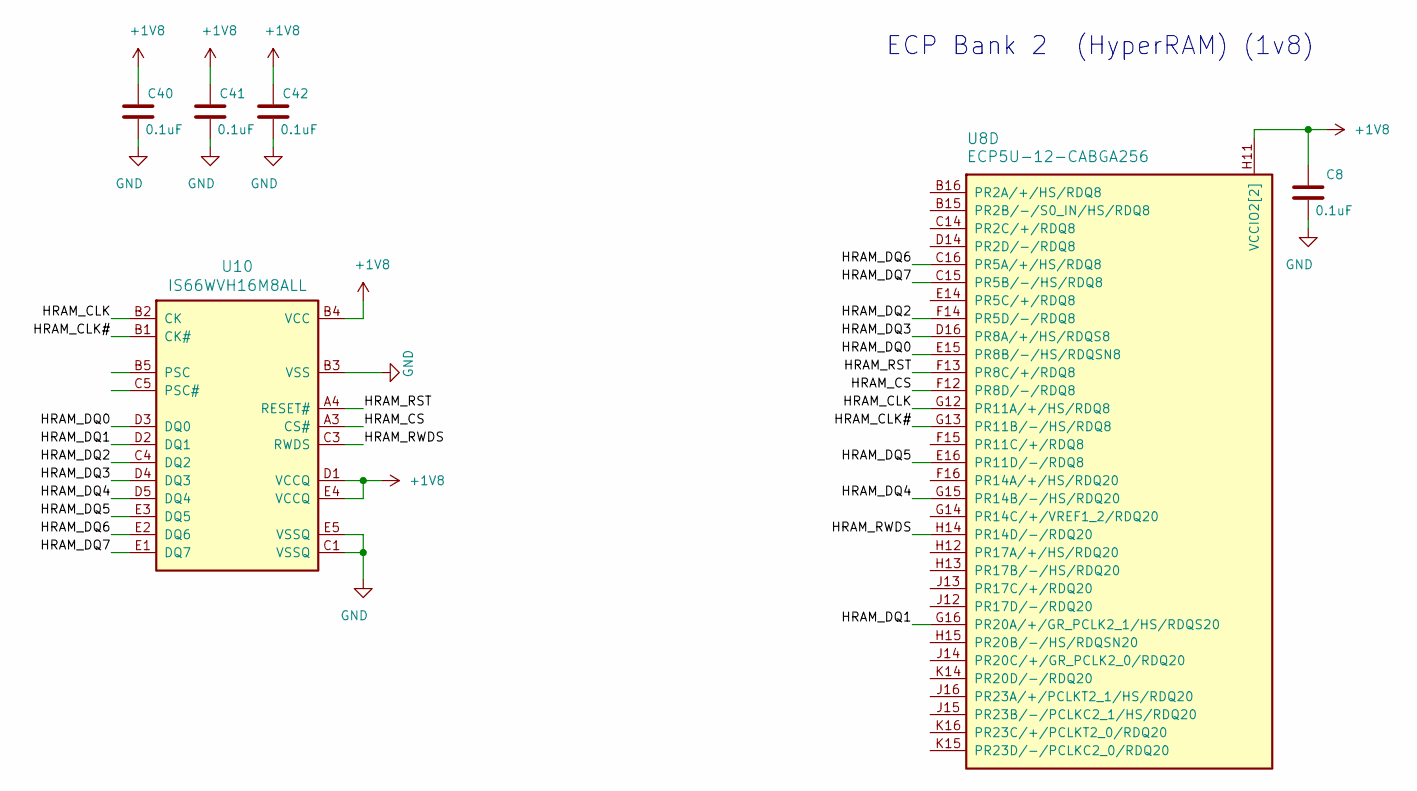
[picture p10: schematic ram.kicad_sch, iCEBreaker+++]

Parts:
C8, C40, C41, C42: 0.1uF; C_0402_1005Metric
U8: ECP5U-12-CABGA256; BGA-256_14.0x14.0mm_Layout16x16_P0.8mm_Ball0.45mm_Pad0.32mm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
U10: IS66WVH16M8ALL; BGA-24_8.0x6.0mm_Layout5x5_P0.8mm_Pad0.35mm_NSMD

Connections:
+1V8: C8.1, C40.1, C41.1, C42.1, U8.H11 (VCCIO2[2]), U8.J11 (VCCIO2[2]), U10.B4 (VCC), U10.D1 (VCCQ), U10.E4 (VCCQ); also elsewhere on the board
/RAM/HRAM_CLK: U8.G12 (PR11A/+/HS/RDQ8), U10.B2 (CK)
/RAM/HRAM_CLK#: U8.G13 (PR11B/-/HS/RDQ8), U10.B1 (CK#)
/RAM/HRAM_CS: U8.F12 (PR8D/-/RDQ8), U10.A3 (CS#)
/RAM/HRAM_DQ0: U8.E15 (PR8B/-/HS/RDQSN8), U10.D3 (DQ0)
/RAM/HRAM_DQ1: U8.G16 (PR20A/+/GR_PCLK2_1/HS/RDQS20), U10.D2 (DQ1)
/RAM/HRAM_DQ2: U8.F14 (PR5D/-/RDQ8), U10.C4 (DQ2)
/RAM/HRAM_DQ3: U8.D16 (PR8A/+/HS/RDQS8), U10.D4 (DQ3)
/RAM/HRAM_DQ4: U8.G15 (PR14B/-/HS/RDQ20), U10.D5 (DQ4)
/RAM/HRAM_DQ5: U8.E16 (PR11D/-/RDQ8), U10.E3 (DQ5)
/RAM/HRAM_DQ6: U8.C16 (PR5A/+/HS/RDQ8), U10.E2 (DQ6)
/RAM/HRAM_DQ7: U8.C15 (PR5B/-/HS/RDQ8), U10.E1 (DQ7)
/RAM/HRAM_RST: U8.F13 (PR8C/+/RDQ8), U10.A4 (RESET#)
/RAM/HRAM_RWDS: U8.H14 (PR14D/-/RDQ20), U10.C3 (RWDS)
GND: C8.2, C40.2, C41.2, C42.2, U10.B3 (VSS), U10.C1 (VSSQ), U10.E5 (VSSQ); also elsewhere on the board

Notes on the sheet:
ECP Bank 2 (HyperRAM) (1v8)

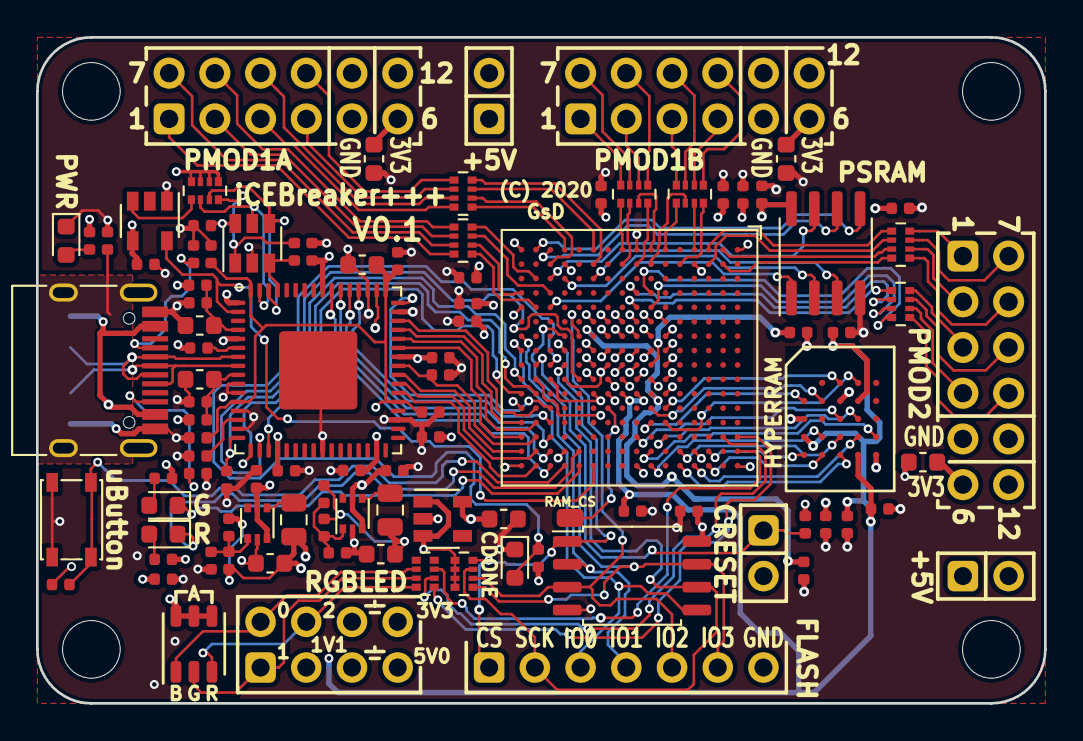
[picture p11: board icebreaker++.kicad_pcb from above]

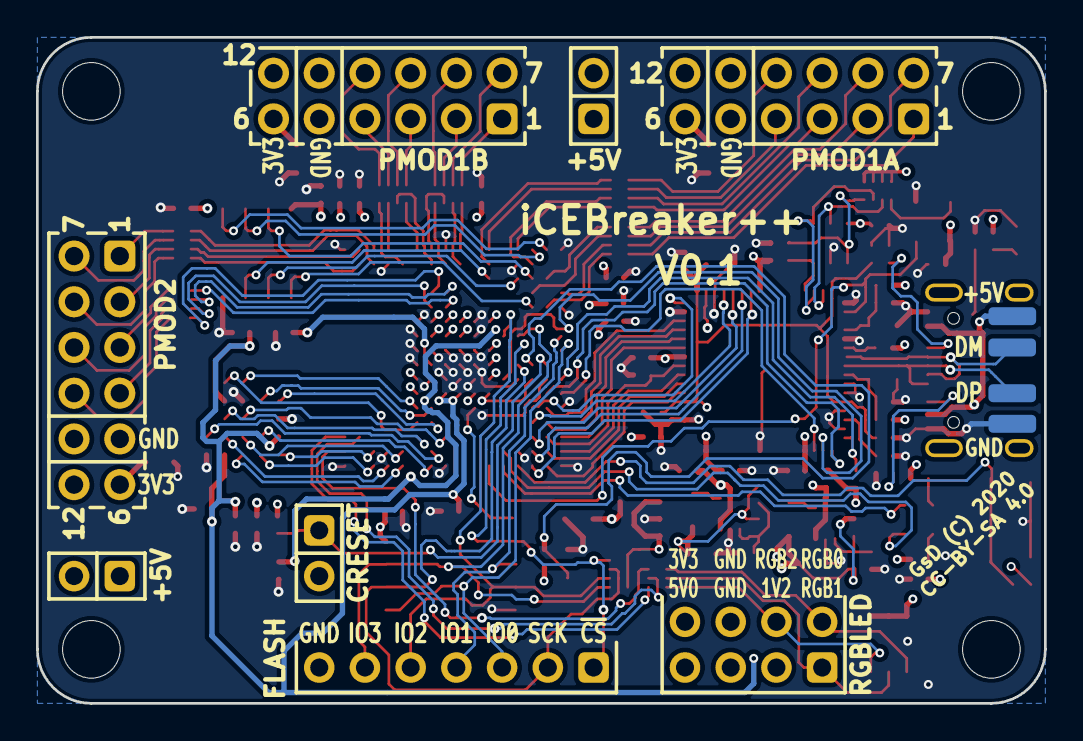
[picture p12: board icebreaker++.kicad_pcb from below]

Board: 4 copper layers, 56.0 x 37.0 mm, 104 parts (4 on the bottom side), 130 nets.

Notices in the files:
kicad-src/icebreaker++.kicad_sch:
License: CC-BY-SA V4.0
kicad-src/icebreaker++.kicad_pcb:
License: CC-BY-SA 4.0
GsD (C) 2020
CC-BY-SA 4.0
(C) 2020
